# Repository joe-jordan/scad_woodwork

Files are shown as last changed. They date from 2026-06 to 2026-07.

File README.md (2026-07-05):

# Woodworking Planning Tool in OpenSCAD

## Workbench (`mft_bench.scad`):

This an early version. Custom modules for all bench parts.

module conventions:
* Each plank needs a file.
* Parts in their own module exist using 0,0 as a plank origin (they may have a tenon, so may not actually arrive at (0,0).)
 * NOTE: since planks know their own dimensions, we can't assume their dimensions in the outer script. This makes computing offsets from the back of the table tricky. Instead, if we "center=true" the parts, then the offsets become centre`<->`centre, and that is calculable from the table constants without knowing the board dimensions.
 * BUT: plenty of offsets are calculated to be registered _on the dimensions_ of the boards, e.g. the tenon offsets inside the legs must be centred. The offset of the centre of the leg is overhang (which itself is calculated based on a board dimension, so aprons are flush) plus half the dimension of the leg. The dimensions of some of the boards detemines the posisions of other boards. which means the dimensions of the boards must also be inputs to the modules.
* z is vertical, and x is the long direction of the bench. All parts know if they are x, y or z grain oriented and appear in that orientation.
* faces that face "inwards" to the centre of the bench are always in modules facing the +x or +y direction.
* Constants about lumber dimensions live in their own module and are exported.
* Constants about the size of the workbench, or the height of shelves, live in the main workbench scad at top level.
* Plank modules accept necessary bench dimensions as arguments, do not pull in globals.

## Worktop (`worktop.scad`)

WIP of a design I have in paper form for a worktop to run alongside the length of a shed wall.

## General Tools (`general_test.scad`)

WIP of a common set of primitives to use in woodwork design:
* Raw Materials represented by the `board` and `sheet` modules.
* Mortice and tenon cuts (square to the board) are then available as modules that take the board or sheet as a child.
* It should be possible to re-build the MFT bench, the worktop, and future projects quickly with this set of tools? To be expanded upon as needed.

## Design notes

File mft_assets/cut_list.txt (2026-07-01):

INPUTS:
  TABLE DIMENSIONS: 
    tt_width = 145,
    tt_height = 100,
    tt_depth = 70
  OTHER NUMBERS:
    floor_to_stretcher = 13,
    overhang = 1.9,
    shelf_groove = 1,
    ttrestle_drop = 2.5,
    key_visible = 6.675

ALL CUT LIST measurements are in cm.

4x4:
CUT LIST: Leg. 4x4 stock (assumed 89mm^2), length = 96.4
CUT LIST: Leg. 4x4 stock (assumed 89mm^2), length = 96.4
CUT LIST: Leg. 4x4 stock (assumed 89mm^2), length = 96.4
CUT LIST: Leg. 4x4 stock (assumed 89mm^2), length = 96.4

18mm Ply:
CUT LIST: Top. Two layers of 18mm ply, width = 70, length = 145
CUT LIST: Shelf. One layer of 18mm ply (maybe as two sections, for ease of installation?), width = 61.1, length = 131.333

2x6:
CUT LIST: apron, 2x6 stock (assumed 140/38mm), length = 141.2
CUT LIST: apron, 2x6 stock (assumed 140/38mm), length = 141.2

2x4:
CUT LIST: top trestle, 2x4 stock (assumed 89/38mm), allow extra length to plane flush with leg., length = 66.2
CUT LIST: top trestle, 2x4 stock (assumed 89/38mm), allow extra length to plane flush with leg., length = 66.2
CUT LIST: bottom trestle, 2x4 stock (assumed 89/38mm), length = 70
CUT LIST: bottom trestle, 2x4 stock (assumed 89/38mm), length = 70
CUT LIST: ankle stretcher, 2x4 stock (assumed 89/38mm), length = 135.267
CUT LIST: ankle stretcher, 2x4 stock (assumed 89/38mm), length = 135.267
CUT LIST: key, 2x4 stock (assumed 89/38mm), length = 70

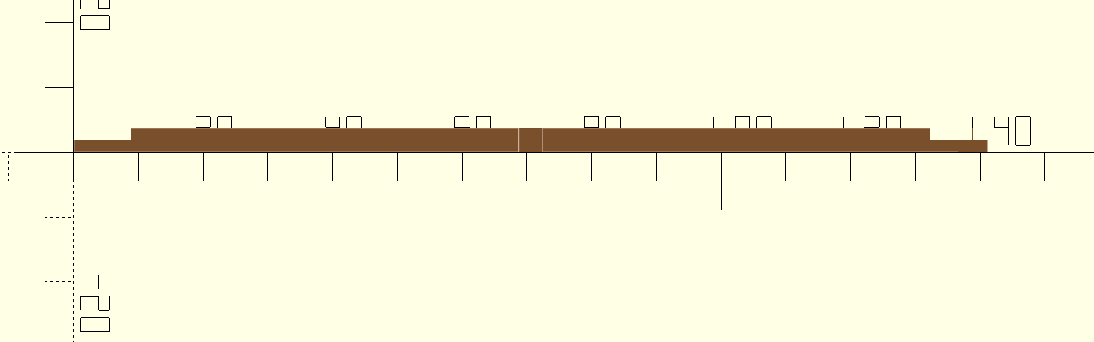
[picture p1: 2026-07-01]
mft_assets/apron_top.png

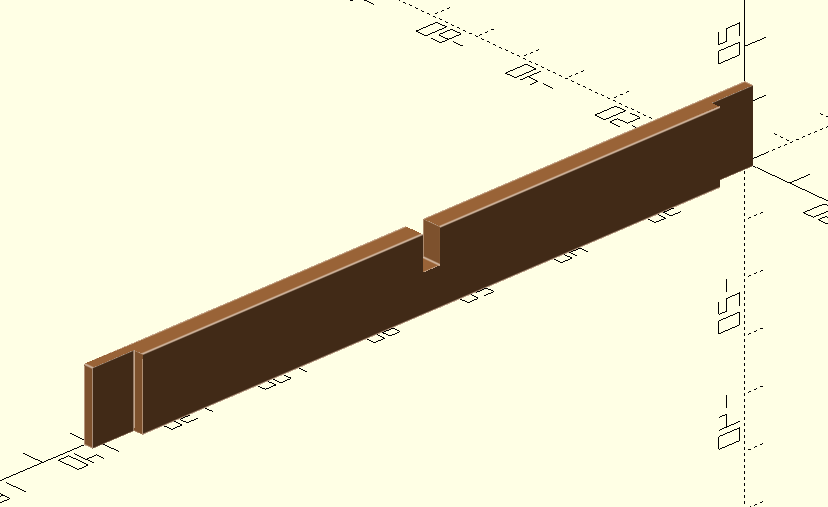
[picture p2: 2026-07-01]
mft_assets/apron.png

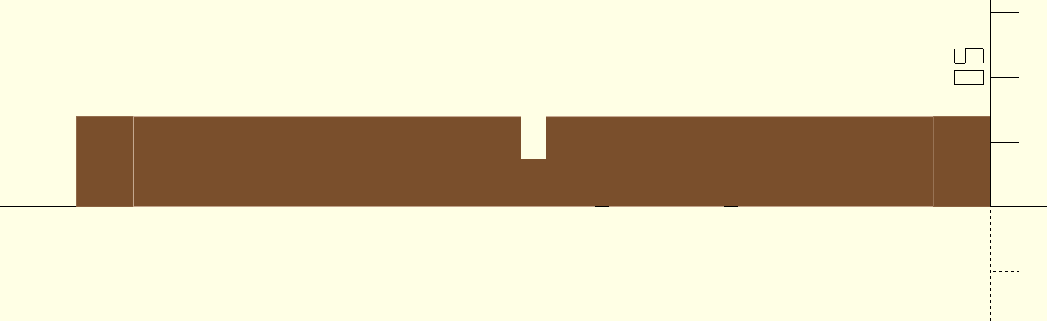
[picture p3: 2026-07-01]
mft_assets/apron_side.png

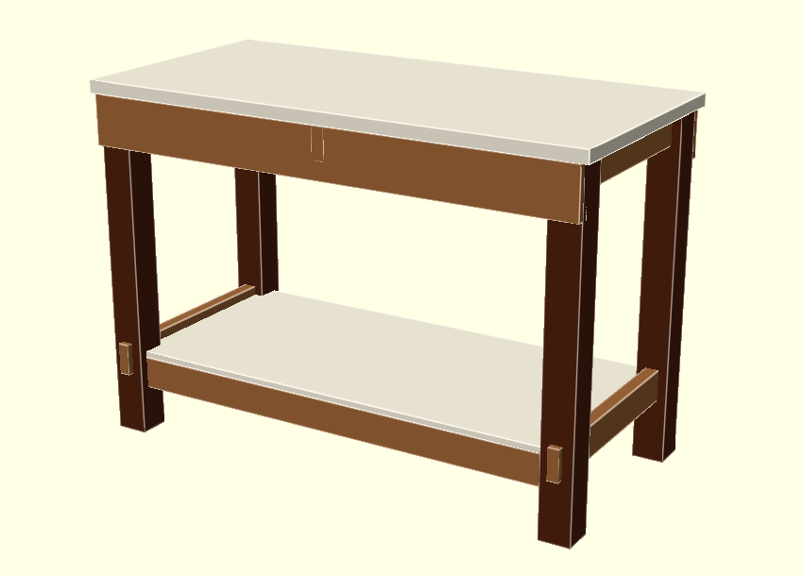
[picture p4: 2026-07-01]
mft_assets/Workbench_full_above.png

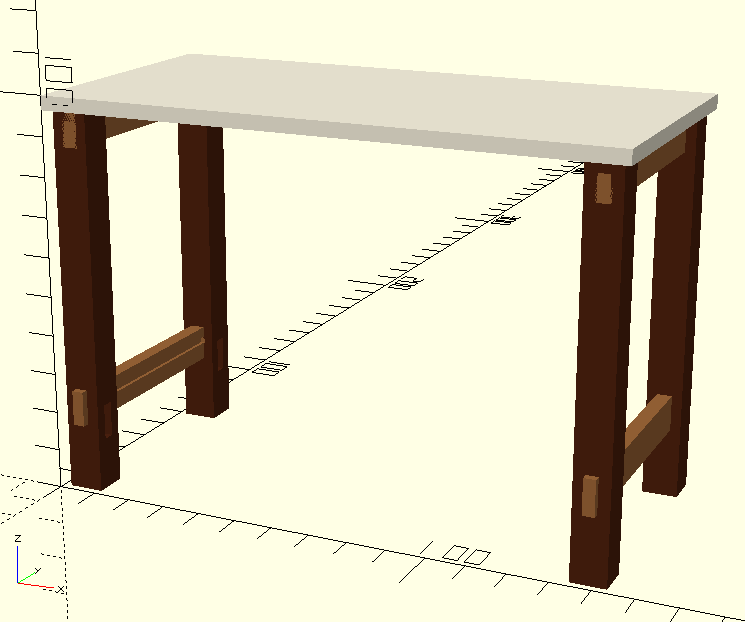
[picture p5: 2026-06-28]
screenshots/workbench_trestles_top.png

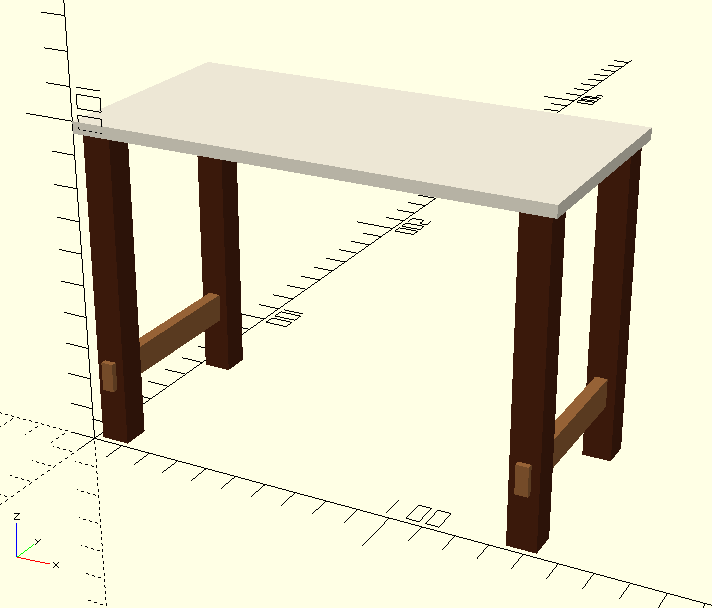
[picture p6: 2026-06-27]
screenshots/workbench_early_preview.png

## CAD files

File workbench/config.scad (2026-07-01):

verbose = true;
mode = "comp";
which_component = "apron";

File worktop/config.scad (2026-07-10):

verbose = true;
mode = "project";
which_component = "runner";

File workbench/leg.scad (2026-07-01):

include<config.scad>
include<lumber_dimensions.scad>

module leg(length, stretcher_z_off, btrestle_z_off, ttrestle_z_drop, mortice_thickness, mortice_offset, mortice_height) {
    // This is half an apron thickness.
    lumber_width = four_by;
    lumber_depth = four_by;

    // stretcher mortices:
    stremor_x_off = mortice_offset;
    stremor_y_off = mortice_offset;
    stremor_z_off = stretcher_z_off;

    stremor_x_size = mortice_thickness + mortice_offset + delta;
    stremor_y_size = mortice_thickness;
    stremor_z_size = mortice_height;

    // bottom trestle mortices:
    btrmor_x_off = mortice_offset;
    btrmor_y_off = -delta;
    btrmor_z_off = btrestle_z_off;

    btrmor_x_size = mortice_thickness;
    btrmor_y_size = lumber_depth + 2*delta;
    btrmor_z_size = mortice_height;

    // top trestle mortices:
    ttrmor_x_off = mortice_offset;
    ttrmor_y_off = -delta;
    ttrmor_z_off = length - mortice_height;

    ttrmor_x_size = mortice_thickness;
    ttrmor_y_size = lumber_depth + 2*delta;
    ttrmor_z_size = mortice_height - ttrestle_z_drop;

    echo ("CUT LIST: Leg. 4x4 stock (assumed 89mm^2)", length=length);

    if (verbose) {
        echo("All mortice widths are 1/3 the stock, set centrally.")
        echo("MORTICE 1: for bottom trestle, through tenon.", position_z=btrmor_z_off, length_z=btrmor_z_size);
        echo("MORTICE 2: for top trestle, through tenon, same orientation as MORTICE 1.", position_z_from_top=ttrestle_z_drop, length_z=ttrmor_z_size);
        echo("MORTICE 3: for stretcher. stop at back of MORTICE 1 (2/3 depth). Offset by 1/2 in z, below MORTICE 1.");
        echo("MORTICE 3 (cont): in the 90deg adjacent face to MORTICE 1 and 2.", position_z=stretcher_z_off, length_z=stremor_z_size);
    }
    color("#4E220F")
    difference() {
        cube([lumber_width, lumber_depth, length], center = false);
        union() {// cuts to make for mortices.
            // stretchers:
            translate([stremor_x_off,stremor_y_off,stremor_z_off]) {
                cube([stremor_x_size,stremor_y_size,stremor_z_size], center=false);
            };
            // lower trestles:
            translate([btrmor_x_off,btrmor_y_off,btrmor_z_off]) {
                cube([btrmor_x_size, btrmor_y_size, btrmor_z_size], center=false);
            };
            // upper trestles:
            translate([ttrmor_x_off,ttrmor_y_off,ttrmor_z_off]) {
                cube([ttrmor_x_size, ttrmor_y_size, ttrmor_z_size], center=false);
            };
        }
    }
}

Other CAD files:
worktop/leg_v2.scad
general/functions.scad
general/half_lap.scad
general/mortice.scad
general/plank.scad
general/sheet.scad
general/tenon.scad
general_test.scad
mft_bench.scad
workbench/apron.scad
workbench/bottom_trestle.scad
workbench/key.scad
workbench/lumber_dimensions.scad
workbench/ply_shelf.scad
workbench/ply_top.scad
workbench/stretcher.scad
workbench/top_trestle.scad
worktop.scad
worktop/leg.scad
worktop/lumber_dimensions.scad
worktop/panel.scad
worktop/ply_top.scad
worktop/runner.scad
worktop/stretcher.scad
worktop/trestle.scad

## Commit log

2026-06-27 initial commit, legs and lower trestle stretchers with solid top. plus screenshot.
    [workbench.scad]
2026-06-27 mortices and grooves in legs and trestles.
    [workbench.scad]
2026-06-27 top trestles and their mortices
    [workbench.scad]
2026-06-28 refactor code to be modular according to new rules (see README), added stretchers.
    [bottom_trestle.scad, leg.scad, lumber_dimensions.scad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]
2026-06-29 tidy ups
    [mft_bench.scad, ply_top.scad]
2026-06-30 shelf and apron.
    [apron.scad, mft_bench.scad, ply_shelf.scad]
2026-07-01 adding the machinery for generating component sheets as well as a cut list/overall view.
    [apron.scad, bottom_trestle.scad, config.scad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]
2026-07-02 rename mode for whole project.
    [mft_bench.scad]
2026-07-02 starting work on the worktops project
    [config.scad, leg.scad, leg_v2.scad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]
2026-07-03 trestle design in, less the extra leg.
    [config.scad, leg.scad, panel.scad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]
2026-07-05 designing more general components from which to compose projects. Plank and Sheet were fairly simple, but Mortice was a pain. Tenon still to do.
    [functions.scad, general_test.scad, mortice.scad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]
2026-07-05 add tenon to general suite with demo tests.
    [general_test.scad, tenon.scad]
2026-07-08 some bugfixes to mortice and tenons (placement of delta slices) and added a half lap cut.
    [general_test.scad, half_lap.scad, mortice.scad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]
2026-07-08 slightly messy changes, but I have the beginning of a runner working using the new half laps.
    [config.scad, leg.scad, lumber_dimensions.scad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]
2026-07-10 finishing touches on the full worktop, need to go back and add cutlist print statements.
    [config.scad, leg_v2.scad, ply_top.scad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]
